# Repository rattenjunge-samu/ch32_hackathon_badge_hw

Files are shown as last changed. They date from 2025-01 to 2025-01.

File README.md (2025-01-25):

# ch32_hackathon_badge_hw

This repo contains all hardware files needed to produce the 2025 hackathon badge.

## Programming

Attach a minichlink with +, - and SWIO to the pin header

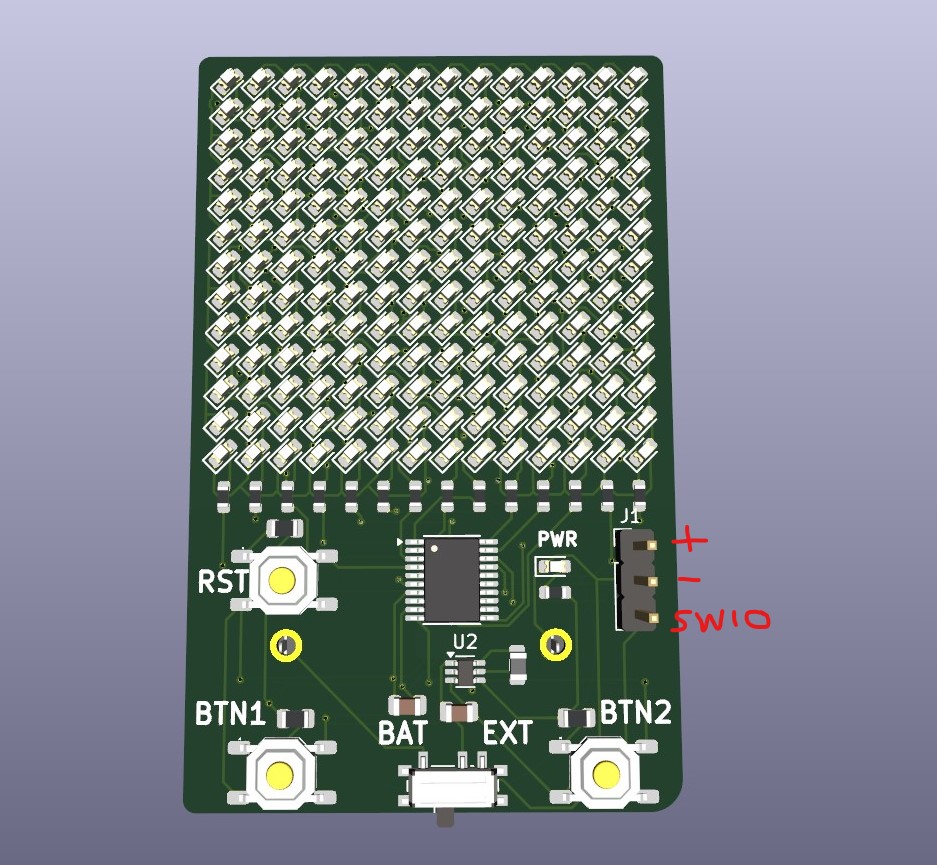
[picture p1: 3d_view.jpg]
hackathon badge


## Revision A

This is the initially produced pcb marked on the back with serial numbers from #00 up to #36.

It needs to be run on two button cells stacked on each other ( = in series)

## Revision B

Not yet produced.

Bugfixes:

- improved layout to hopefully work on a single button cell
  - big thank you to [prozessorkern](https://github.com/prozessorkern/)

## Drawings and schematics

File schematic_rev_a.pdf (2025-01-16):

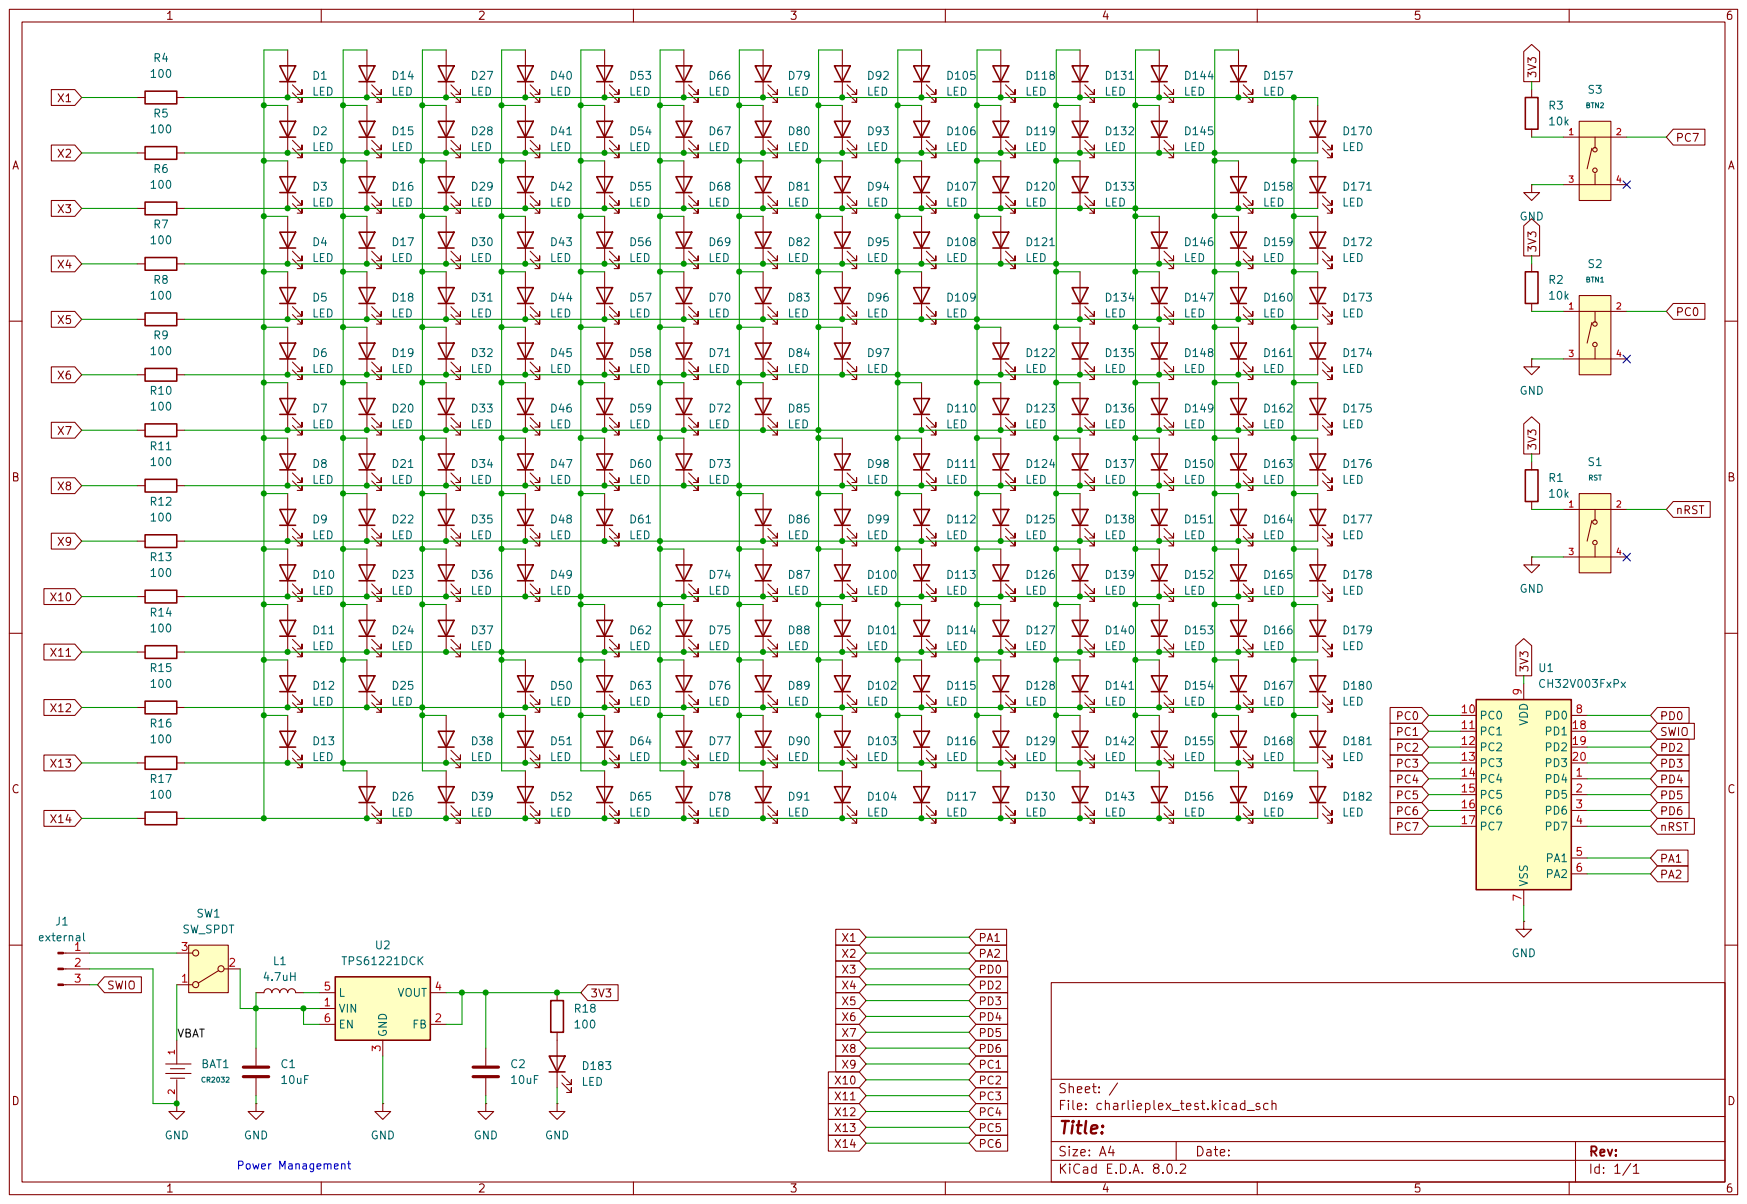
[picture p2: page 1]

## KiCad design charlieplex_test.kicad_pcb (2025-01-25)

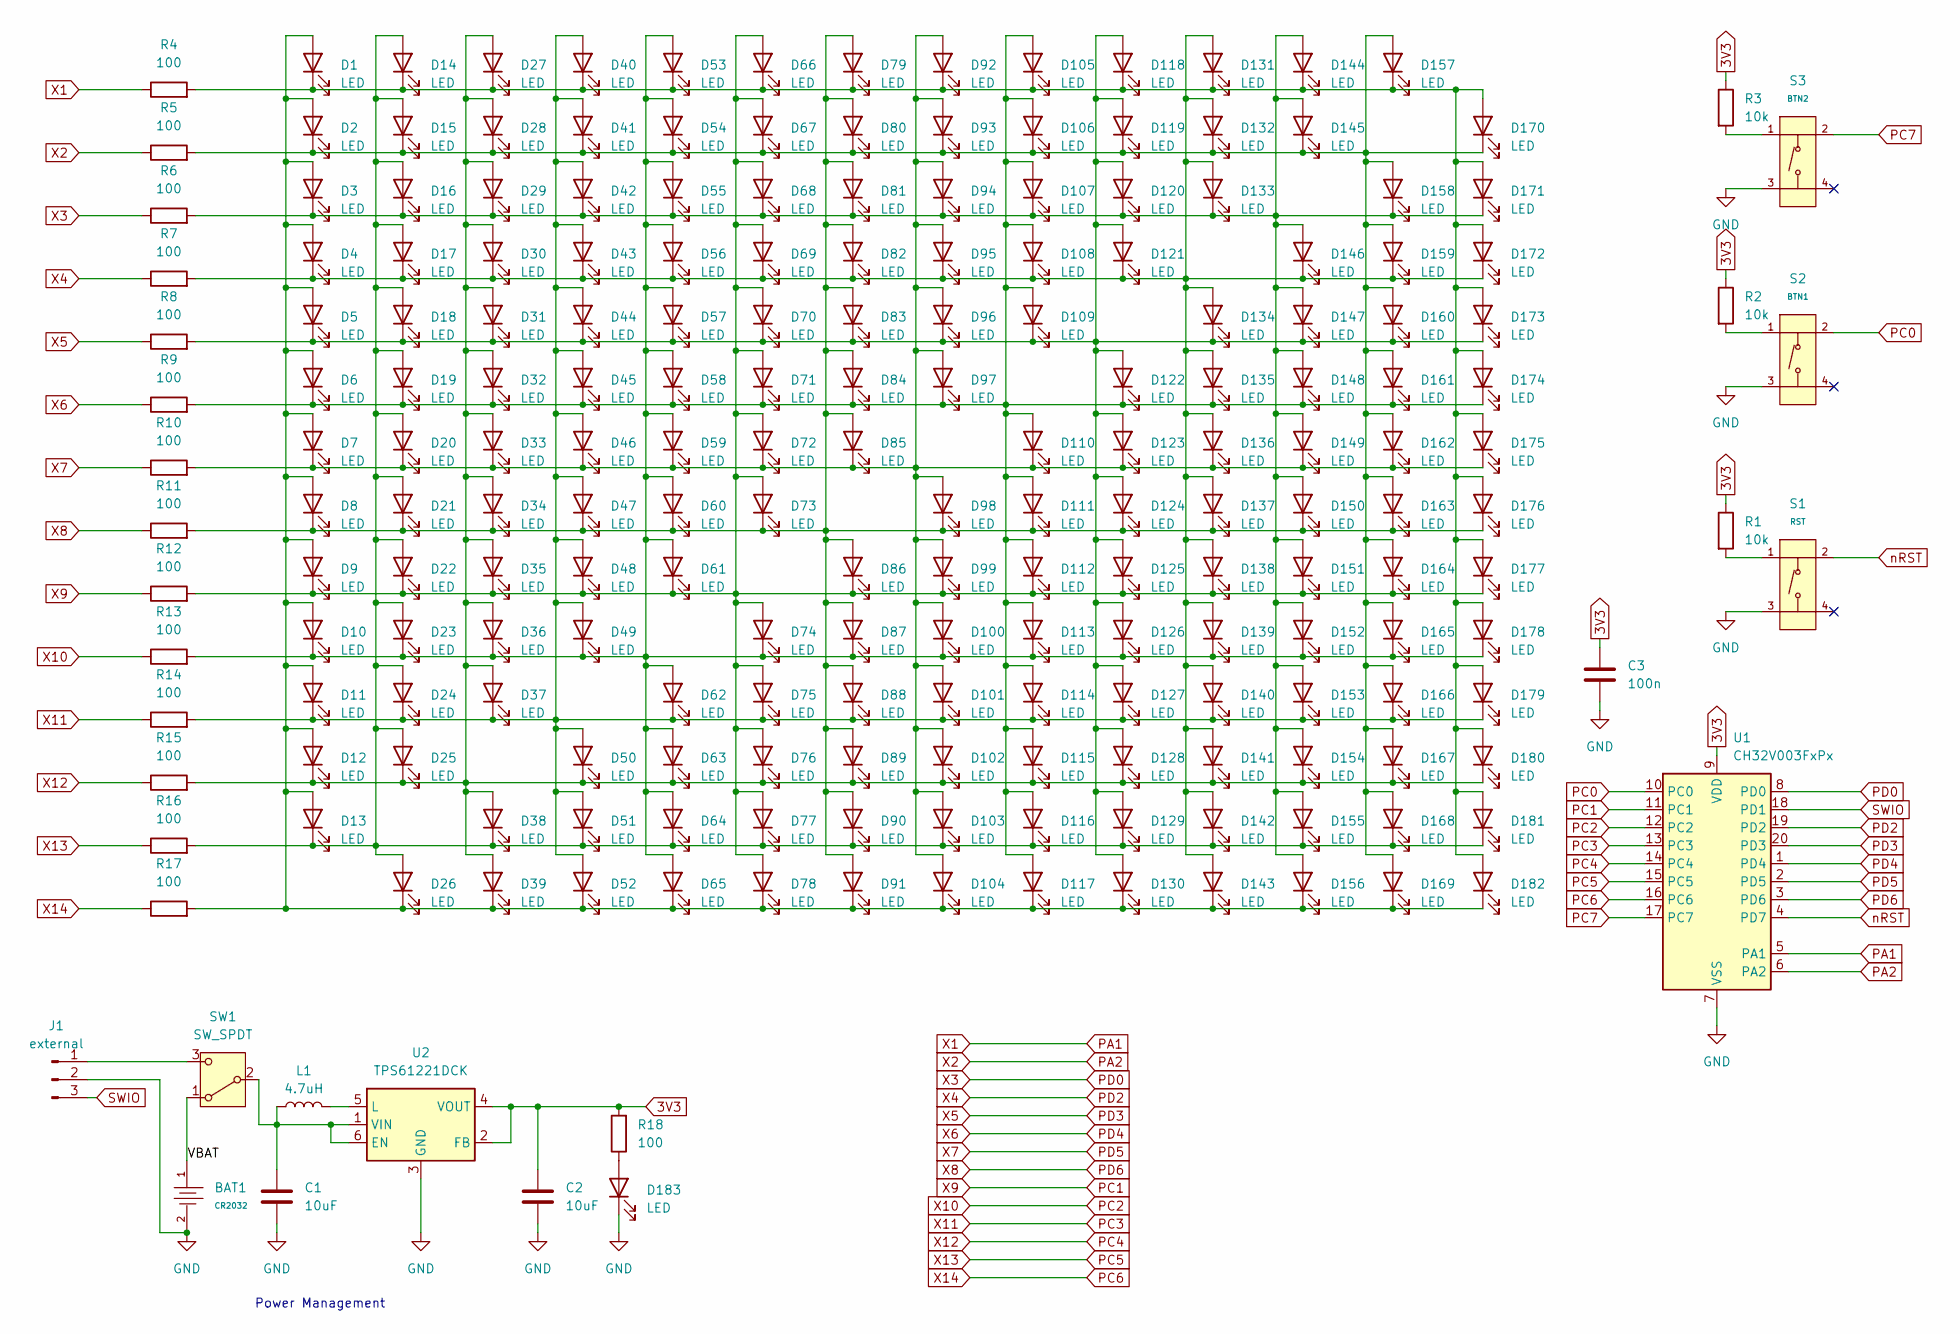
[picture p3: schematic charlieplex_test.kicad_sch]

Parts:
BAT1: CR2032; BAT-TH_BS-07-A1BJ001; Part BS-07-A1BJ001; LCSC C2979167
C1, C2: 10uF; C_0805
C3: 100n; C_0603_1608Metric
D1, D2, D3, D4, D5, D6, D7, D8, D9, D10, D11, D12, D13, D14, D15, D16, D17, D18, D19, D20, D21, D22, D23, D24, D25, D26, D27, D28, D29, D30, D31, D32, D33, D34, D35, D36, D37, D38, D39, D40, D41, D42, D43, D44, D45, D46, D47, D48, D49, D50, D51, D52, D53, D54, D55, D56, D57, D58, D59, D60, D61, D62, D63, D64, D65, D66, D67, D68, D69, D70, D71, D72, D73, D74, D75, D76, D77, D78, D79, D80, D81, D82, D83, D84, D85, D86, D87, D88, D89, D90, D91, D92, D93, D94, D95, D96, D97, D98, D99, D100, D101, D102, D103, D104, D105, D106, D107, D108, D109, D110, D111, D112, D113, D114, D115, D116, D117, D118, D119, D120, D121, D122, D123, D124, D125, D126, D127, D128, D129, D130, D131, D132, D133, D134, D135, D136, D137, D138, D139, D140, D141, D142, D143, D144, D145, D146, D147, D148, D149, D150, D151, D152, D153, D154, D155, D156, D157, D158, D159, D160, D161, D162, D163, D164, D165, D166, D167, D168, D169, D170, D171, D172, D173, D174, D175, D176, D177, D178, D179, D180, D181, D182, D183: LED; D_0603
J1: external; PinHeader_1x03_P2.54mm_Vertical
L1: 4.7uH; L_0805
R1, R2, R3: 10k; R_0805
R4, R5, R6, R7, R8, R9, R10, R11, R12, R13, R14, R15, R16, R17, R18: 100; R_0603
S1: RST; SW-SMD_4P-L5.1-W5.1-P3.70-LS6.5-TL-2; Voltage Rating (Dc) 12V; Part TS-1187A-B-A-B; LCSC C318884
S2: BTN1; SW-SMD_4P-L5.1-W5.1-P3.70-LS6.5-TL-2; Voltage Rating (Dc) 12V; Part TS-1187A-B-A-B; LCSC C318884
S3: BTN2; SW-SMD_4P-L5.1-W5.1-P3.70-LS6.5-TL-2; Voltage Rating (Dc) 12V; Part TS-1187A-B-A-B; LCSC C318884
SW1: SW_SPDT; SW_SPDT_PCM12
U1: CH32V003FxPx; TSSOP-20_4.4x6.5mm_P0.65mm
U2: TPS61221DCK; Texas_R-PDSO-G6

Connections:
3V3: C2.1, C3.1, R1.1, R2.1, R3.1, R18.2, U1.9 (VDD), U2.2 (FB), U2.4 (VOUT)
/VBAT: BAT1.1, SW1.1 (A)
GND: BAT1.2, C1.2, C2.2, C3.2, D183.1 (K), J1.2, S1.3 (C), S2.3 (C), S3.3 (C), U1.7 (VSS), U2.3 (GND)
unnamed: D1.2 (A), D2.2 (A), D3.2 (A), D4.2 (A), D5.2 (A), D6.2 (A), D7.2 (A), D8.2 (A), D9.2 (A), D10.2 (A), D11.2 (A), D12.2 (A), D13.2 (A), D26.1 (K), D39.1 (K), D52.1 (K), D65.1 (K), D78.1 (K), D91.1 (K), D104.1 (K), D117.1 (K), D130.1 (K), D143.1 (K), D156.1 (K), D169.1 (K), D182.1 (K), R17.2
unnamed: D1.1 (K), D14.1 (K), D27.1 (K), D40.1 (K), D53.1 (K), D66.1 (K), D79.1 (K), D92.1 (K), D105.1 (K), D118.1 (K), D131.1 (K), D144.1 (K), D157.1 (K), D170.2 (A), D171.2 (A), D172.2 (A), D173.2 (A), D174.2 (A), D175.2 (A), D176.2 (A), D177.2 (A), D178.2 (A), D179.2 (A), D180.2 (A), D181.2 (A), D182.2 (A), R4.2
unnamed: D10.1 (K), D23.1 (K), D36.1 (K), D49.1 (K), D53.2 (A), D54.2 (A), D55.2 (A), D56.2 (A), D57.2 (A), D58.2 (A), D59.2 (A), D60.2 (A), D61.2 (A), D62.2 (A), D63.2 (A), D64.2 (A), D65.2 (A), D74.1 (K), D87.1 (K), D100.1 (K), D113.1 (K), D126.1 (K), D139.1 (K), D152.1 (K), D165.1 (K), D178.1 (K), R13.2
unnamed: D7.1 (K), D20.1 (K), D33.1 (K), D46.1 (K), D59.1 (K), D72.1 (K), D85.1 (K), D92.2 (A), D93.2 (A), D94.2 (A), D95.2 (A), D96.2 (A), D97.2 (A), D98.2 (A), D99.2 (A), D100.2 (A), D101.2 (A), D102.2 (A), D103.2 (A), D104.2 (A), D110.1 (K), D123.1 (K), D136.1 (K), D149.1 (K), D162.1 (K), D175.1 (K), R10.2
unnamed: D11.1 (K), D24.1 (K), D37.1 (K), D40.2 (A), D41.2 (A), D42.2 (A), D43.2 (A), D44.2 (A), D45.2 (A), D46.2 (A), D47.2 (A), D48.2 (A), D49.2 (A), D50.2 (A), D51.2 (A), D52.2 (A), D62.1 (K), D75.1 (K), D88.1 (K), D101.1 (K), D114.1 (K), D127.1 (K), D140.1 (K), D153.1 (K), D166.1 (K), D179.1 (K), R14.2
unnamed: D12.1 (K), D25.1 (K), D27.2 (A), D28.2 (A), D29.2 (A), D30.2 (A), D31.2 (A), D32.2 (A), D33.2 (A), D34.2 (A), D35.2 (A), D36.2 (A), D37.2 (A), D38.2 (A), D39.2 (A), D50.1 (K), D63.1 (K), D76.1 (K), D89.1 (K), D102.1 (K), D115.1 (K), D128.1 (K), D141.1 (K), D154.1 (K), D167.1 (K), D180.1 (K), R15.2
unnamed: D13.1 (K), D14.2 (A), D15.2 (A), D16.2 (A), D17.2 (A), D18.2 (A), D19.2 (A), D20.2 (A), D21.2 (A), D22.2 (A), D23.2 (A), D24.2 (A), D25.2 (A), D26.2 (A), D38.1 (K), D51.1 (K), D64.1 (K), D77.1 (K), D90.1 (K), D103.1 (K), D116.1 (K), D129.1 (K), D142.1 (K), D155.1 (K), D168.1 (K), D181.1 (K), R16.2
unnamed: D6.1 (K), D19.1 (K), D32.1 (K), D45.1 (K), D58.1 (K), D71.1 (K), D84.1 (K), D97.1 (K), D105.2 (A), D106.2 (A), D107.2 (A), D108.2 (A), D109.2 (A), D110.2 (A), D111.2 (A), D112.2 (A), D113.2 (A), D114.2 (A), D115.2 (A), D116.2 (A), D117.2 (A), D122.1 (K), D135.1 (K), D148.1 (K), D161.1 (K), D174.1 (K), R9.2
unnamed: D2.1 (K), D15.1 (K), D28.1 (K), D41.1 (K), D54.1 (K), D67.1 (K), D80.1 (K), D93.1 (K), D106.1 (K), D119.1 (K), D132.1 (K), D145.1 (K), D157.2 (A), D158.2 (A), D159.2 (A), D160.2 (A), D161.2 (A), D162.2 (A), D163.2 (A), D164.2 (A), D165.2 (A), D166.2 (A), D167.2 (A), D168.2 (A), D169.2 (A), D170.1 (K), R5.2
unnamed: D3.1 (K), D16.1 (K), D29.1 (K), D42.1 (K), D55.1 (K), D68.1 (K), D81.1 (K), D94.1 (K), D107.1 (K), D120.1 (K), D133.1 (K), D144.2 (A), D145.2 (A), D146.2 (A), D147.2 (A), D148.2 (A), D149.2 (A), D150.2 (A), D151.2 (A), D152.2 (A), D153.2 (A), D154.2 (A), D155.2 (A), D156.2 (A), D158.1 (K), D171.1 (K), R6.2
unnamed: D4.1 (K), D17.1 (K), D30.1 (K), D43.1 (K), D56.1 (K), D69.1 (K), D82.1 (K), D95.1 (K), D108.1 (K), D121.1 (K), D131.2 (A), D132.2 (A), D133.2 (A), D134.2 (A), D135.2 (A), D136.2 (A), D137.2 (A), D138.2 (A), D139.2 (A), D140.2 (A), D141.2 (A), D142.2 (A), D143.2 (A), D146.1 (K), D159.1 (K), D172.1 (K), R7.2
unnamed: D5.1 (K), D18.1 (K), D31.1 (K), D44.1 (K), D57.1 (K), D70.1 (K), D83.1 (K), D96.1 (K), D109.1 (K), D118.2 (A), D119.2 (A), D120.2 (A), D121.2 (A), D122.2 (A), D123.2 (A), D124.2 (A), D125.2 (A), D126.2 (A), D127.2 (A), D128.2 (A), D129.2 (A), D130.2 (A), D134.1 (K), D147.1 (K), D160.1 (K), D173.1 (K), R8.2
unnamed: D8.1 (K), D21.1 (K), D34.1 (K), D47.1 (K), D60.1 (K), D73.1 (K), D79.2 (A), D80.2 (A), D81.2 (A), D82.2 (A), D83.2 (A), D84.2 (A), D85.2 (A), D86.2 (A), D87.2 (A), D88.2 (A), D89.2 (A), D90.2 (A), D91.2 (A), D98.1 (K), D111.1 (K), D124.1 (K), D137.1 (K), D150.1 (K), D163.1 (K), D176.1 (K), R11.2
unnamed: D9.1 (K), D22.1 (K), D35.1 (K), D48.1 (K), D61.1 (K), D66.2 (A), D67.2 (A), D68.2 (A), D69.2 (A), D70.2 (A), D71.2 (A), D72.2 (A), D73.2 (A), D74.2 (A), D75.2 (A), D76.2 (A), D77.2 (A), D78.2 (A), D86.1 (K), D99.1 (K), D112.1 (K), D125.1 (K), D138.1 (K), D151.1 (K), D164.1 (K), D177.1 (K), R12.2
unnamed: D183.2 (A), R18.1
unnamed: J1.1, SW1.3 (C)
unnamed: R1.2, S1.1 (A)
unnamed: R2.2, S2.1 (A)
unnamed: R3.2, S3.1 (A)
unnamed: C1.1, L1.1, SW1.2 (B), U2.1 (VIN), U2.6 (EN)
unnamed: L1.2, U2.5 (L)
PA1: R4.1, U1.5 (PA1)
PA2: R5.1, U1.6 (PA2)
PC0: S2.2 (B), U1.10 (PC0)
PC1: R12.1, U1.11 (PC1)
PC2: R13.1, U1.12 (PC2)
PC3: R14.1, U1.13 (PC3)
PC4: R15.1, U1.14 (PC4)
PC5: R16.1, U1.15 (PC5)
PC6: R17.1, U1.16 (PC6)
PC7: S3.2 (B), U1.17 (PC7)
PD0: R6.1, U1.8 (PD0)
PD2: R7.1, U1.19 (PD2)
PD3: R8.1, U1.20 (PD3)
PD4: R9.1, U1.1 (PD4)
PD5: R10.1, U1.2 (PD5)
PD6: R11.1, U1.3 (PD6)
SWIO: J1.3, U1.18 (PD1)
nRST: S1.2 (B), U1.4 (PD7)

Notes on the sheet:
Power Management

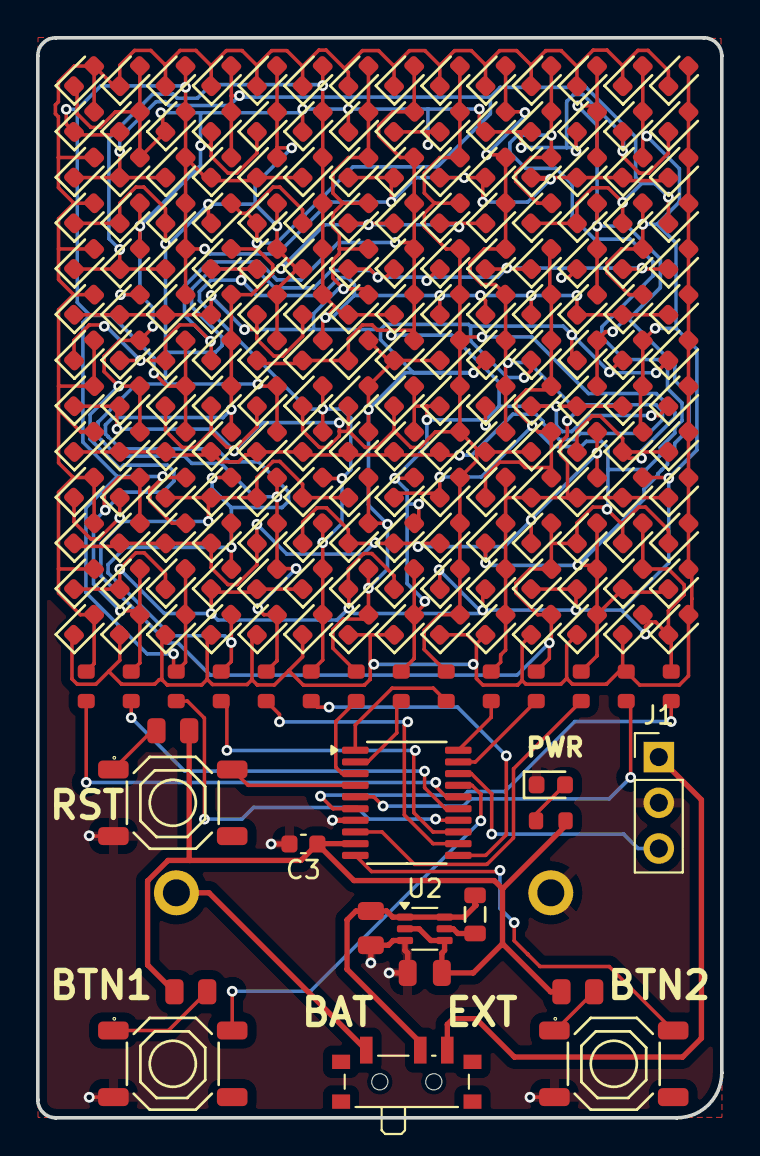
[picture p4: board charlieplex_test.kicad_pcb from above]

Board: 2 copper layers, 38.0 x 60.0 mm, 213 parts (1 on the bottom side), 42 nets.

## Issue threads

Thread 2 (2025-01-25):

Doesn't run on single CR2032

rattenjunge-samu, 2025-01-25:
The TPS61221 should be able to create a feasable 3V3 signal from 0.7 V to 5.5 V on VBAT

But it doesn't work with a single button cell. Stack a second one on the first and it works.

Closed 2025-01-25.
